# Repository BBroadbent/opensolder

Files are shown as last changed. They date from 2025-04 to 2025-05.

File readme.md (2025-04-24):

# OpenSolder
Fully open source JBC T245-compatible soldering station and tool holder  


## Introduction
When my cheap T12 clone soldering station went up in smoke, I started looking into either buying a JBC CDB, or building a proper soldering station. The internet is already crowded with DIY JBC compatible stations, but most are poorly documented, or does not have the quality-of-life features that the original have.

The [unisolder project](https://github.com/sparkybg/UniSolder-5.2) is very impressive, but way to complex and "universal" for my needs. [Marco Reps](https://youtu.be/GYIiOkr6x9o) built a cool C470 station that i liked the simplicity of, and this project is highly inspired by that.

## Goals:
- _T12 clone_ form factor that does not take up valuable bench space
- JBC T245 tip compatibility, with similar performance to the original station
- QoL features that the CDB station have, like auto standby, tip remover, holder, tip cleaner etc.
- Simple design using cheap off-the-shelf parts
- A compact handpiece stand with these features:
	- Detection when the handpiece is in the tool holder (auto standby)
	- Detection when you're about to swap tips (cut power)
	- Integrated tip remover, tip storage, tip cleaner and a soldering wire spool holder
	- Simple to build

## Design Specifications
- 24V toroidal transformer
- Zero Crossing AC switching
- OLED display and rotary encoder for adjusting temperature
- Compact and low profile design
- Super fast heatup time (~4s)
- Hardware should be mostly 3D printable, and easy to build using regular tools

## Station
  
The station is built in a Hammond enclosure, with a center mounted transformer. The PCB is mounted to the custom front panel, and all 230VAC connections is in the rear of the chassis.
There is two connectors on the rear panel, one for connecting to the stand, and an optional ST-link connector for firmware upgrades.

## Stand
  
The stand is made of 3D-printed parts, a genuine JBC tool holder, a tip remover made from aluminium angle and some fasteners. Most parts can be made from aluminium sheet if that is preferred.

## Schematic
This is the internal connections of the JBC C245 cartridge:  
  

[__The schematic__](https://github.com/howie-j/OpenSolder/raw/main/hardware/schematic.pdf) is divided into three sheets: AC, Analog and MCU.

### AC
The 24VAC input is fused, then connected directly to the tip center pin (5). Switching is done with two N-channel mosfets, driven by a Si8751 isolated gate driver.

Zero cross detection is done with an AC optocoupler, and the current is limited by three 10k resistors (to reduce BOM items). This solution triggers the ZeroCross about 90uS prematurely, and that is compensated for in firmware.

The MCU and thermocouple frontend must be electrically isolated, and a 24V to 5V DCDC PSU module solves that problem. The DCDC-supply is preregulated with a 24V linear regulator, and post-regulated to 3.3V with a LDO. This power supply chain is in need of some simplification, but the components are few and cheap, and it works great for now.

### Analog
The thermocouple signal is amplified with a MAX4238 chopper opamp, with a fairly arbitrary amplification of 221, since temperature calibration is done in firmware anyway. No negative supply rail means the thermocouple can't sense lower temperatures than room temp, but that's not needed for a soldering station.

Long handpiece wires means lots of crosstalk, so a pair of diodes clamps the thermocouple input at Vf. The MCU pin _TIP_CLAMP_ is driven low when power is applied to the handpiece, to clamp noise on the opamp input. When its time to measure tip temperature, the pin is set to input, and a delay waits for the RC filter to stabilize.

To sense if there is a tip cartridge in the handpiece, _TIP_CHECK_ is driven high. The low impedance of the thermocouple + heater (a few Ω's) will create a very low voltage drop. If the tip is removed, the Vf of the input protection diode will drive _THERMOCOUPLE_ADC_ close to 3.3V.

### MCU
A STM32F072 is used since I have a few of them in stock, but almost any STM32 could be adapted to work. To sense PCB temperature (and for cold junction compensation), an I2C temp sensor is added. The MCU might have an internal temperature sensor, but  have not looked into that yet.

The rotary encoder and handpiece stand inputs are filtered using plain RC filters. This, combined with the input hysteresis, removes most input noise. The TIM encoder inputs also have additional filtering and FSM redundancy.

## PCB
[___Check out this interactive BOM___](http://htmlpreview.github.io/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)

  
  
The PCB is quite low density, uses 0805 SMD components and is fully hand solderable with a microscope. Connections to the rear connectors (stand and ST-link) is done via a 6-pin IDC connector, so no crimping of tiny connector pins are necessary. The PCB is mounted to the front panel via the rotary encoder and the handpiece connector.

## Firmware
The firmware is simple and functional, and uses a modified hysteresis temperature controller that is very fast but has some initial overshoot. Currently all default values are set in _opensolder.h_, and are reset when the station is powered off.

### TODO
Nothing is currently missing for regular functionality. However some features would be cool to have:

- More accurate temp control (PID or other controller)
- User changeable default values
- Menu for changing default values
- Better looking UI

### B Broadbent TODO
- Pullup on zero cross line (external to STM32) (10k)

## Links and Sources
[The unisolder project](https://github.com/sparkybg/UniSolder-5.2)  
[Marco Reps](https://youtu.be/GYIiOkr6x9o)  
[foldvarid93's JBC Soldering Station](https://github.com/foldvarid93/JBC_SolderingStation)  
[johnmx's eevblog thread](https://eevblog.com/forum/testgear/jbc-soldering-station-cd-2bc-complete-schematic-analysis/)

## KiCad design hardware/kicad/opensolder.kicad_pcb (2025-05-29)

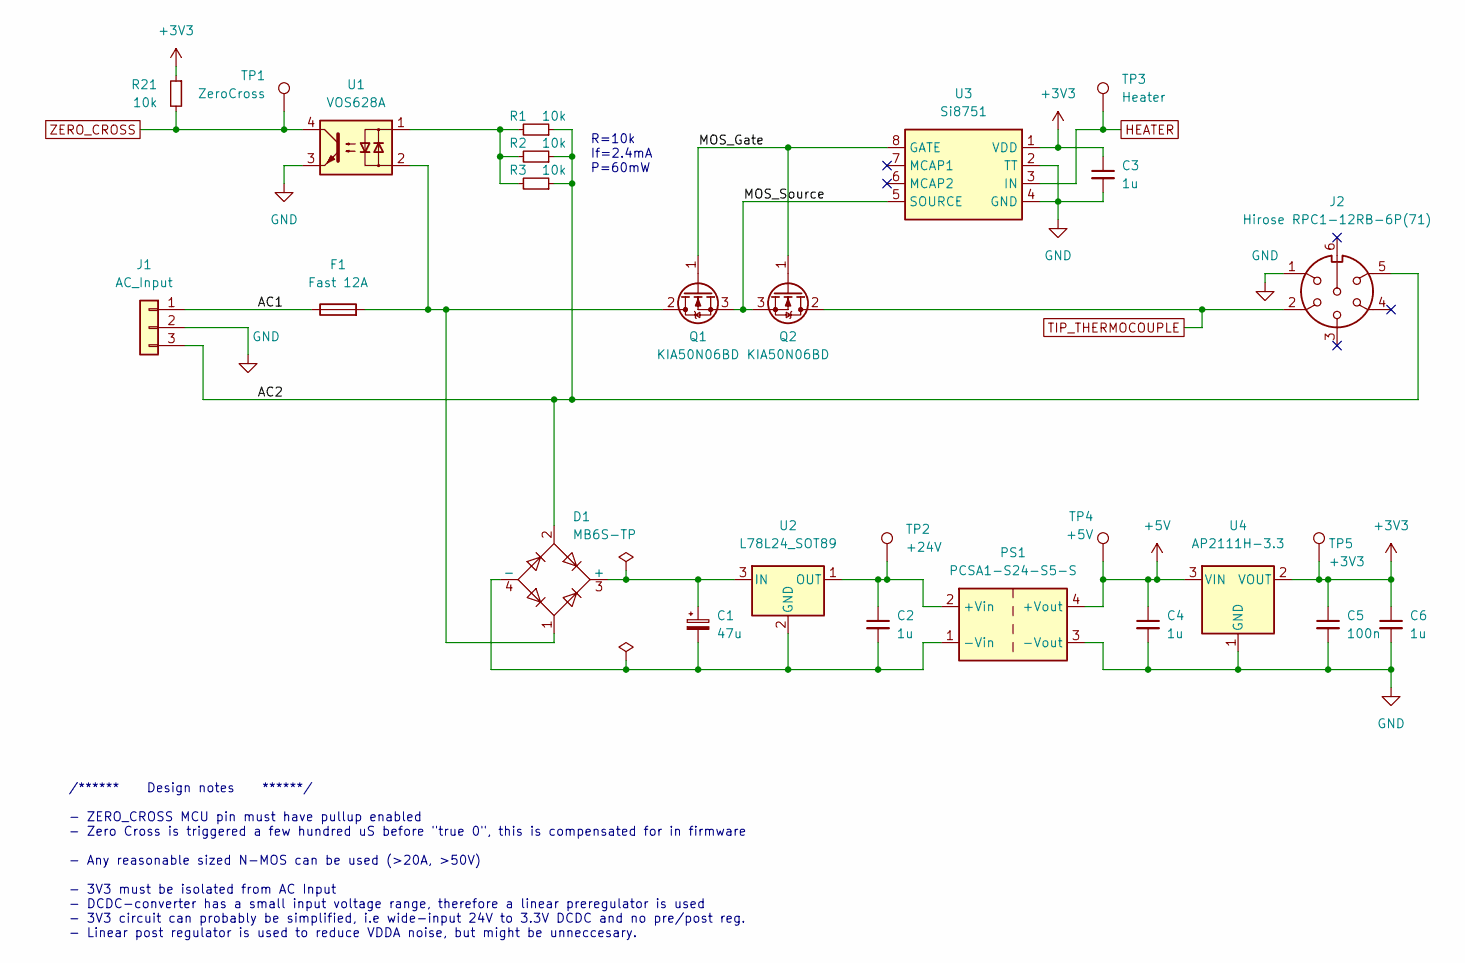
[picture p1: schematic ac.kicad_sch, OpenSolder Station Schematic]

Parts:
C1: 47u; CP_Radial_D8.0mm_P3.50mm
C2, C3, C4, C6: 1u; C_1210_3225Metric
C5: 100n; C_0805_2012Metric
D1: MB6S-TP; TO-269AA
F1: Fast 12A; Fuseholder_Cylinder-5x20mm_Schurter_0031_8201_Horizontal_Op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
J1: AC_Input; PhoenixContact_MSTBVA_2,5_3-G_1x03_P5.00mm_Vertical
J2: Hirose RPC1-12RB-6P(71); Hirose_RPC1
PS1: PCSA1-S24-S5-S; PDSE1_DCDC
Q1, Q2: KIA50N06BD; TO-252-2
R1, R2, R3, R21: 10k; R_0805_2012Metric
TP1: ZeroCross; TestPoint_Pad_D1.0mm
TP2: +24V; TestPoint_Pad_D1.0mm
TP3: Heater; TestPoint_Pad_D1.0mm
TP4: +5V; TestPoint_Pad_D1.0mm
TP5: +3V3; TestPoint_Pad_D1.0mm
U1: VOS628A; SOP-4_4.4x2.6mm_P1.27mm
U2: L78L24_SOT89; SOT-89-3
U3: Si8751; SOIC-8_3.9x4.9mm_P1.27mm
U4: AP2111H-3.3; SOT-223

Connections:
+3V3: C3.1, C5.1, C6.1, R21.1, TP5.1, U3.1 (VDD), U4.2 (VOUT); also elsewhere on the board
+5V: C4.1, PS1.4 (+Vout), TP4.1, U4.3 (VIN)
/AC/AC1: F1.1, J1.1
/AC/AC2: D1.2, J1.3, J2.5, R1.1, R2.1, R3.1
/AC/MOS_Gate: Q1.1 (G), Q2.1 (G), U3.8 (GATE)
/AC/MOS_Source: Q1.3 (S), Q2.3 (S), U3.5 (SOURCE)
GND: C3.2, C4.2, C5.2, C6.2, J1.2, J2.1, PS1.3 (-Vout), U1.3, U3.2 (TT), U3.4 (GND), U4.1 (GND); also elsewhere on the board
HEATER: TP3.1, U3.3 (IN); also elsewhere on the board
unnamed: C1.1, D1.3 (+), U2.3 (IN)
unnamed: C1.2, C2.2, D1.4 (-), PS1.1 (-Vin), U2.2 (GND)
unnamed: C2.1, PS1.2 (+Vin), TP2.1, U2.1 (OUT)
unnamed: D1.1, F1.2, Q1.2 (D), U1.2
unnamed: R1.2, R2.2, R3.2, U1.1
TIP_THERMOCOUPLE: J2.2, Q2.2 (D); also elsewhere on the board
ZERO_CROSS: R21.2, TP1.1, U1.4; also elsewhere on the board

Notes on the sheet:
R=10k If=2.4mA P=60mW
/****** Design notes ******/ - ZERO_CROSS MCU pin must have pullup enabled - Zero Cross is triggered a few hundred uS before "true 0", this is compensated for in firmware - Any reasonable sized N-MOS can be used (>20A, >50V) - 3V3 must be isolated from AC Input - DCDC-converter has a small input vo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

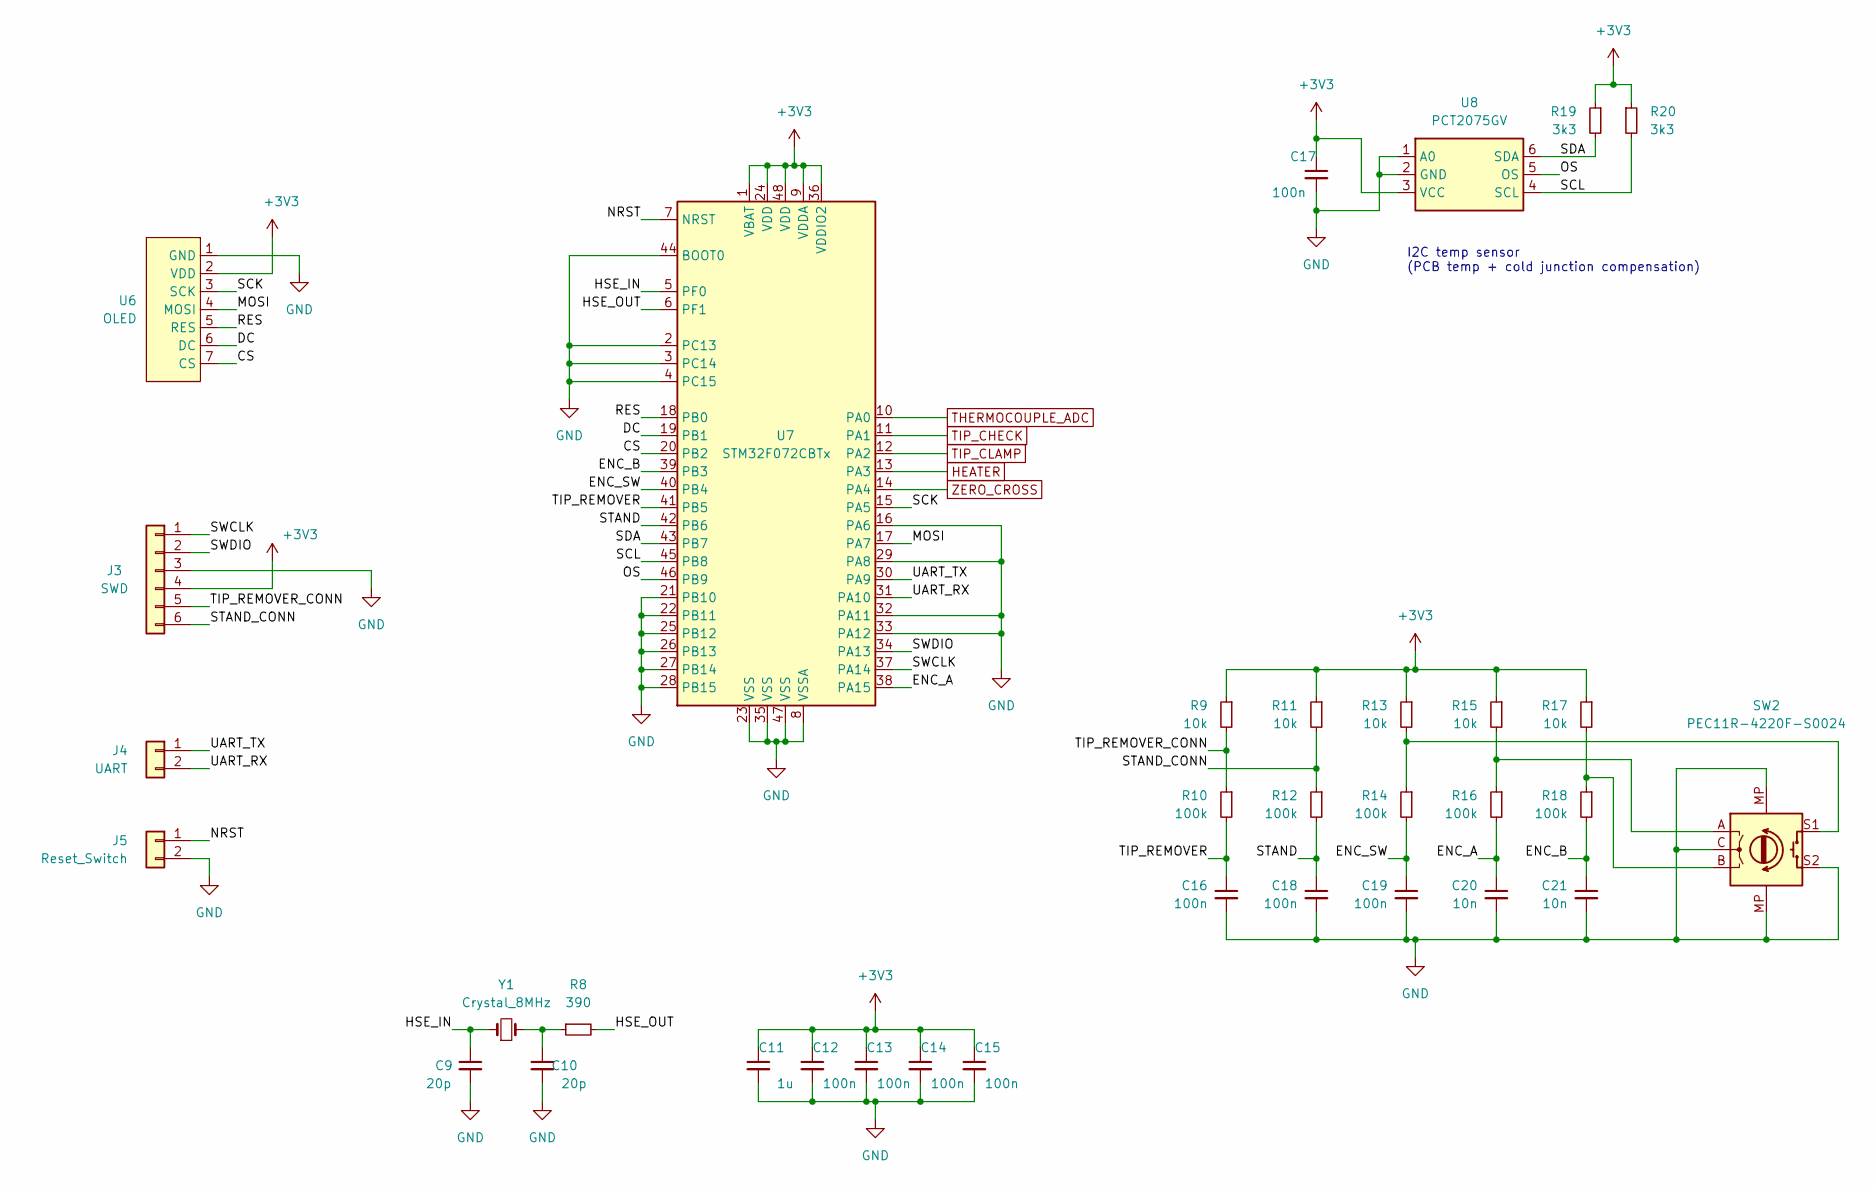
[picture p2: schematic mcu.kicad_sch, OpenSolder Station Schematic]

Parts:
C9, C10: 20p; C_0805_2012Metric
C11: 1u; C_1210_3225Metric
C12, C13, C14, C15, C16, C17, C18, C19: 100n; C_0805_2012Metric
C20, C21: 10n; C_0805_2012Metric
J3: SWD; IDC-Header_2x03_P2.54mm_Vertical
J4: UART; PinSocket_1x02_P2.54mm_Vertical
J5: Reset_Switch; PinSocket_1x02_P2.54mm_Vertical
R8: 390; R_0805_2012Metric
R9, R11, R13, R15, R17: 10k; R_0805_2012Metric
R10, R12, R14, R16, R18: 100k; R_0805_2012Metric
R19, R20: 3k3; R_0805_2012Metric
SW2: PEC11R-4220F-S0024; RotaryEncoder_PEC11R_PEC12R
U6: OLED; OLED_SSD1306_SPI_1.54
U7: STM32F072CBTx; LQFP-48_7x7mm_P0.5mm
U8: PCT2075GV; TSOP-6_1.65x3.05mm_P0.95mm
Y1: Crystal_8MHz; Crystal_SMD_HC49-SD

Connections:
+3V3: C11.1, C12.1, C13.1, C14.1, C15.1, C17.1, J3.4, R9.1, R11.1, R13.1, R15.1, R17.1, R19.1, R20.1, U6.2 (VDD), U7.1 (VBAT), U7.9 (VDDA), U7.24 (VDD), U7.36 (VDDIO2), U7.48 (VDD), U8.3 (VCC); also elsewhere on the board
/MCU/CS: U6.7 (CS), U7.20 (PB2)
/MCU/DC: U6.6 (DC), U7.19 (PB1)
/MCU/ENC_A: C20.1, R16.2, U7.38 (PA15)
/MCU/ENC_B: C21.1, R18.2, U7.39 (PB3)
/MCU/ENC_SW: C19.1, R14.2, U7.40 (PB4)
/MCU/HSE_IN: C9.1, U7.5 (PF0), Y1.1
/MCU/HSE_OUT: R8.2, U7.6 (PF1)
/MCU/MOSI: U6.4 (MOSI), U7.17 (PA7)
/MCU/NRST: J5.1, U7.7 (NRST)
/MCU/OS: U7.46 (PB9), U8.5 (OS)
/MCU/RES: U6.5 (RES), U7.18 (PB0)
/MCU/SCK: U6.3 (SCK), U7.15 (PA5)
/MCU/SCL: R20.2, U7.45 (PB8), U8.4 (SCL)
/MCU/SDA: R19.2, U7.43 (PB7), U8.6 (SDA)
/MCU/STAND: C18.1, R12.2, U7.42 (PB6)
/MCU/STAND_CONN: J3.6, R11.2, R12.1
/MCU/SWCLK: J3.1, U7.37 (PA14)
/MCU/SWDIO: J3.2, U7.34 (PA13)
/MCU/TIP_REMOVER: C16.1, R10.2, U7.41 (PB5)
/MCU/TIP_REMOVER_CONN: J3.5, R9.2, R10.1
/MCU/UART_RX: J4.2, U7.31 (PA10)
/MCU/UART_TX: J4.1, U7.30 (PA9)
GND: C9.2, C10.2, C11.2, C12.2, C13.2, C14.2, C15.2, C16.2, C17.2, C18.2, C19.2, C20.2, C21.2, J3.3, J5.2, SW2.C, SW2.MP, SW2.S2, U6.1 (GND), U7.2 (PC13), U7.3 (PC14), U7.4 (PC15), U7.8 (VSSA), U7.16 (PA6), U7.21 (PB10), U7.22 (PB11), U7.23 (VSS), U7.25 (PB12), U7.26 (PB13), U7.27 (PB14), U7.28 (PB15), U7.29 (PA8), U7.32 (PA11), U7.33 (PA12), U7.35 (VSS), U7.44 (BOOT0), U7.47 (VSS), U8.1 (A0), U8.2 (GND); also elsewhere on the board
HEATER: U7.13 (PA3); also elsewhere on the board
unnamed: C10.1, R8.1, Y1.2
unnamed: R13.2, R14.1, SW2.S1
unnamed: R15.2, R16.1, SW2.A
unnamed: R17.2, R18.1, SW2.B
THERMOCOUPLE_ADC: U7.10 (PA0); also elsewhere on the board
TIP_CHECK: U7.11 (PA1); also elsewhere on the board
TIP_CLAMP: U7.12 (PA2); also elsewhere on the board
ZERO_CROSS: U7.14 (PA4); also elsewhere on the board

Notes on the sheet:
I2C temp sensor (PCB temp + cold junction compensation)

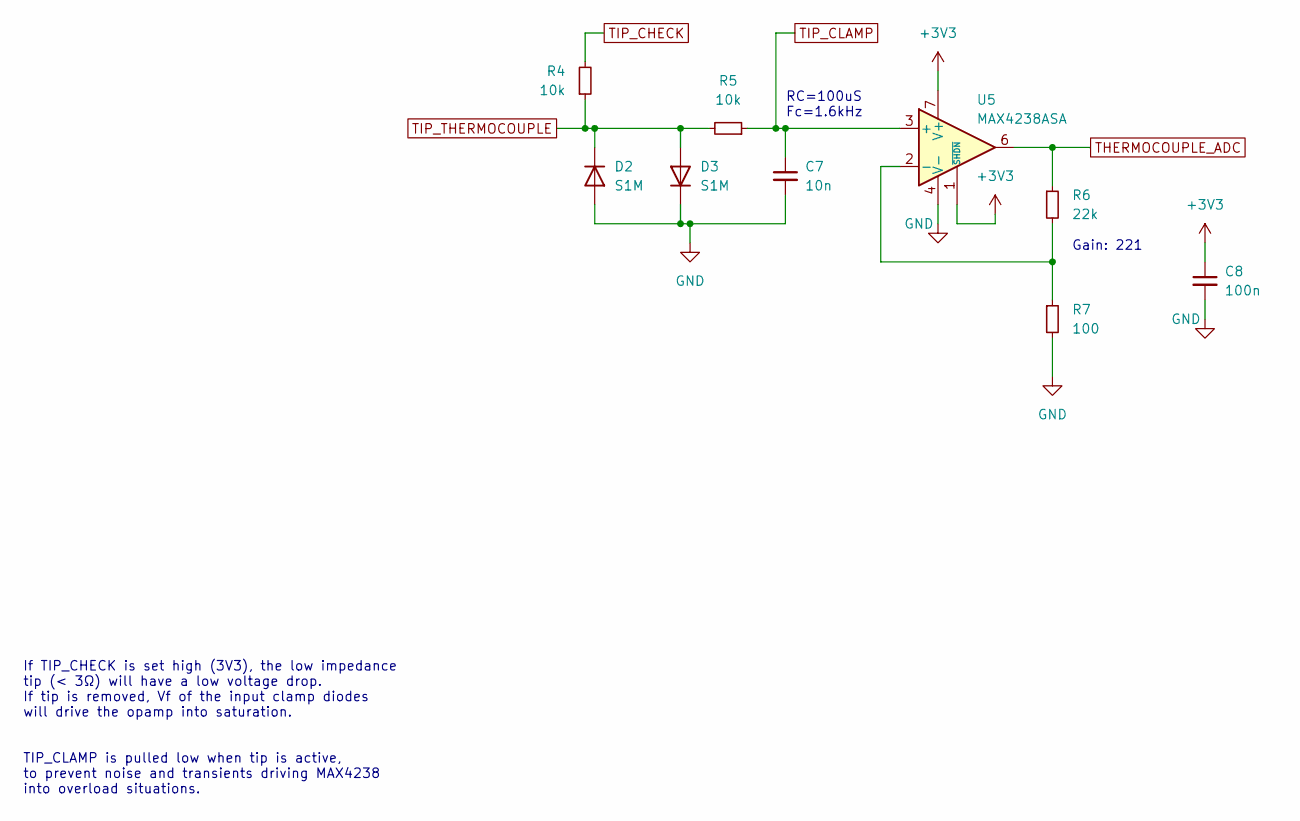
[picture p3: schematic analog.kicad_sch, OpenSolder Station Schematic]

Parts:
C7: 10n; C_0805_2012Metric
C8: 100n; C_0805_2012Metric
D2, D3: S1M; D_SMA
R4, R5: 10k; R_0805_2012Metric
R6: 22k; R_0805_2012Metric
R7: 100; R_0805_2012Metric
U5: MAX4238ASA; SOIC-8_3.9x4.9mm_P1.27mm

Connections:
+3V3: C8.1, U5.1 (~SHDN), U5.7 (V+); also elsewhere on the board
GND: C7.2, C8.2, D2.2 (A), D3.1 (K), R7.2, U5.4 (V-); also elsewhere on the board
unnamed: R6.2, R7.1, U5.2 (-)
THERMOCOUPLE_ADC: R6.1, U5.6; also elsewhere on the board
TIP_CHECK: R4.2; also elsewhere on the board
TIP_CLAMP: C7.1, R5.1, U5.3 (+); also elsewhere on the board
TIP_THERMOCOUPLE: D2.1 (K), D3.2 (A), R4.1, R5.2; also elsewhere on the board

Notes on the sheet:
Gain: 221
RC=100uS Fc=1.6kHz
If TIP_CHECK is set high (3V3), the low impedance tip (< 3Ω) will have a low voltage drop. If tip is removed, Vf of the input clamp diodes will drive the opamp into saturation. TIP_CLAMP is pulled low when tip is active, to prevent noise and transients driving MAX4238 into overload situations.

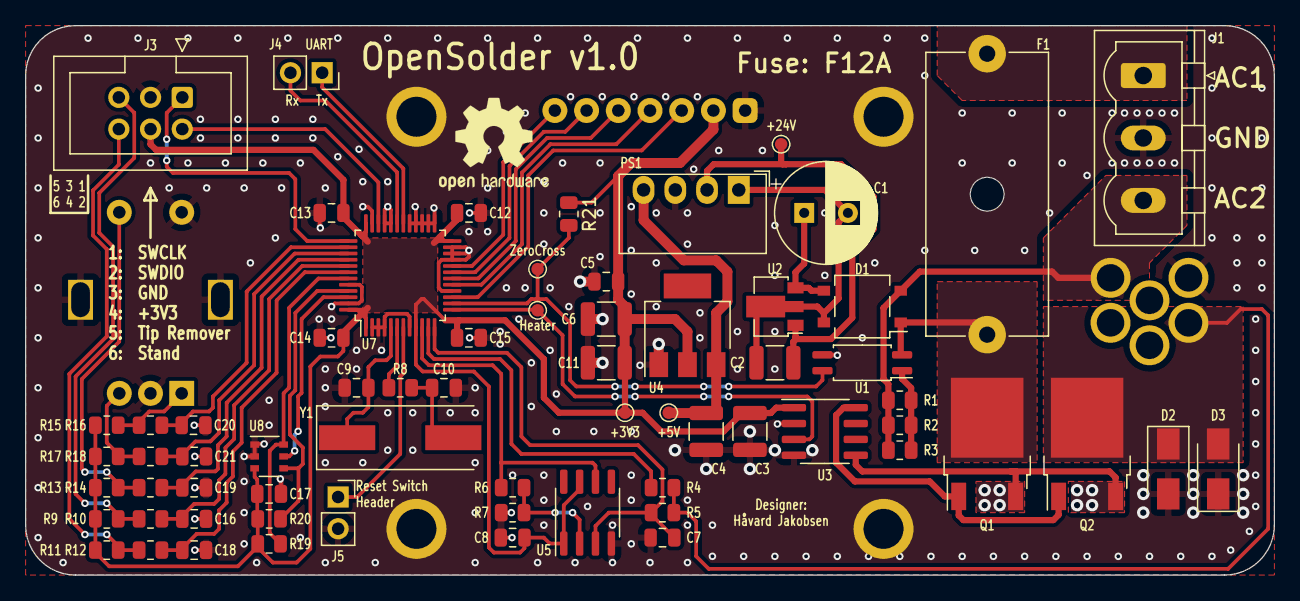
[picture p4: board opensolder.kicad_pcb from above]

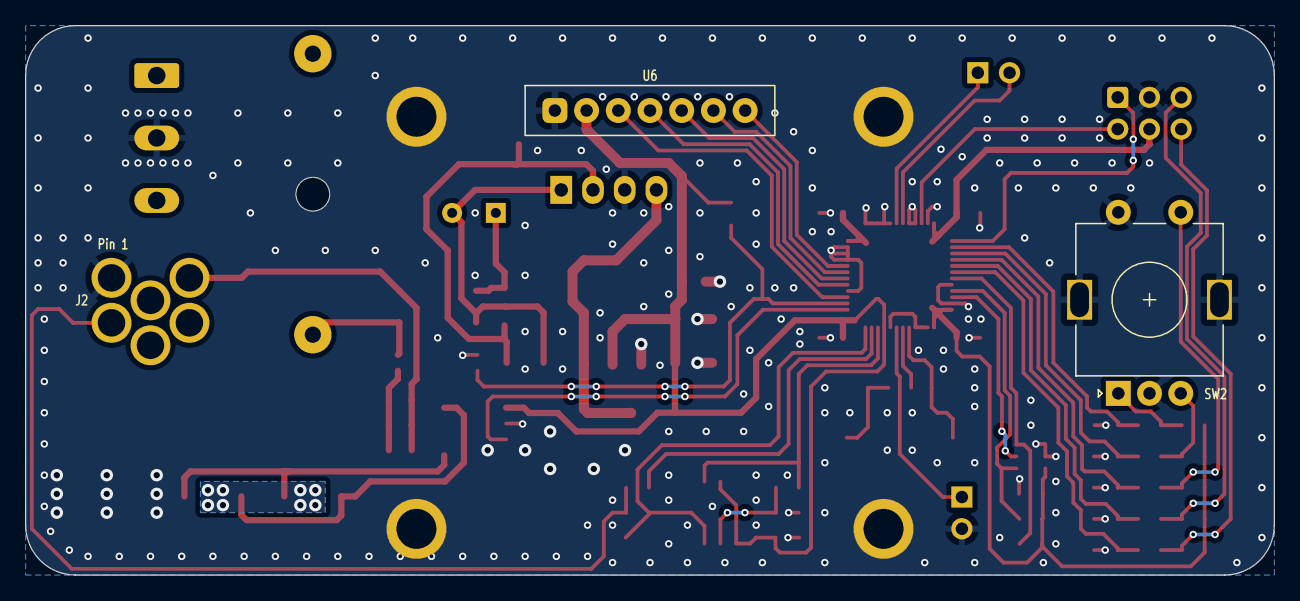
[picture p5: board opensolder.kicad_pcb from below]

Board: 2 copper layers, 100.0 x 44.0 mm, 69 parts (3 on the bottom side), 45 nets.

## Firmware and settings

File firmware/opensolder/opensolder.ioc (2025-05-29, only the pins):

Mcu.UserName=STM32F072CBTx
PA0.GPIO_Label=THERMOCOUPLE_ADC
PA0.Signal=ADC_IN0
PA1.GPIO_Label=TIP_CHECK
PA1.Signal=GPIO_Input
PA10.Signal=USART1_RX
PA13.Signal=SYS_SWDIO
PA14.Signal=SYS_SWCLK
PA15.GPIO_Label=ENC_A
PA15.Signal=S_TIM2_CH1_ETR
PA2.GPIO_Label=TIP_CLAMP
PA2.Signal=GPIO_Input
PA3.GPIO_Label=HEATER
PA3.Signal=GPIO_Output
PA4.GPIO_Label=ZERO_CROSS
PA4.Signal=GPXTI4
PA5.Signal=SPI1_SCK
PA7.Signal=SPI1_MOSI
PA9.Signal=USART1_TX
PB0.GPIO_Label=RES
PB0.Signal=GPIO_Output
PB1.GPIO_Label=DC
PB1.Signal=GPIO_Output
PB2.GPIO_Label=CS
PB2.Signal=GPIO_Output
PB3.GPIO_Label=ENC_B
PB3.Signal=S_TIM2_CH2
PB4.GPIO_Label=ENC_SW
PB4.Signal=GPIO_Input
PB5.GPIO_Label=TIP_REMOVER
PB5.Signal=GPIO_Input
PB6.GPIO_Label=STAND
PB6.Signal=GPIO_Input
PB7.Signal=I2C1_SDA
PB8.Signal=I2C1_SCL
PB9.GPIO_Label=OS
PB9.Signal=GPIO_Input
PF0-OSC_IN.Signal=RCC_OSC_IN
PF1-OSC_OUT.Signal=RCC_OSC_OUT

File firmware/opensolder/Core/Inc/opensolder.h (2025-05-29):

/*
 * opensolder.h
 *
 * License: GPL-3.0 or any later version
 * Copyright (c) 2022 Håvard Jakobsen
 */

#ifndef OPENSOLDER_H
#define OPENSOLDER_H

/******    Includes    ******/
#include "main.h"
#include <stdint.h>

/******    Constants   ******/
enum PCT2075_constants {
	PCT2075_I2C_ADDR = 0x92U, // 1001 001 << 1
	PCT2075_TEMP_REG = 0x00U, // Temperature register pointer
	PCT2075_CONF_REG = 0x01U, // Configuration register pointer
	PCT2075_HYST_REG = 0x02U, // Hysteresis register pointer
	PCT2075_OS_REG = 0x03U,	  // Over-temperature shutdown register pointer
	PCT2075_IDLE_REG = 0x01U  // Idle register pointer
};

enum opensolder_constants {
	TIP_CHECK_INTERVAL = 50,		   // Number of half mains cycles between each tip check (value of 50 cycles * 10ms = 500ms tipcheck interval)
	TIP_CHANGE_DELAY_MS = 2000,		   // Delay after tip_change_sense is set before turning heater on
	DISPLAY_BRIGHTNESS = 255,		   // Sets display contrast/brightness, value 0-255
	DISPLAY_UPDATE_TICKS = 500,		   // Refresh rate for updating tip_temp, set higher to remove jitter
	DISPLAY_MESSAGE_TIMEOUT_MS = 2000, // How long to display messages
	STR_ARRAY_MAX_LEN = 128 / 6 + 1,	   // Display text string array max length (including '\0'.
	SPLASHSCREEN_TIMEOUT_MS = 1000,	   // Splash screen / boot screen, 0 to disable
	DEFAULT_TEMP = 320,				   // Default set temp on startup
	MAX_TEMP = 420,					   // Maximum allowable temperature
	MIN_TEMP = 30,					   // Minimum allowable temperature
	TEMP_STEPS = 5,					   // Number of degrees setTemp changes per encoder step
	MAX_ON_PERIODS = 4,				   // Maximum number if AC half cycles the power should be on before next temp reading
	STANDBY_TEMP = 160,				   // Tip temperature when handle is in holder
	STANDBY_TIME_S = 300,			   // Number of seconds to keep tip at elevated standby temperature, before turning heater off
	STANDBY_DELAY_MS = 300,			   // Delay from lifting the tool holder before turning heater on
	ADC_BUFFER_LENGTH = 50,			   // Number of ADC samples to take every reading
	ADC_MAX_DEVIATION = 200,		   // Maximum deviation allowed in the ADC sample buffer. Any value out of range gives the reading an error
	ADC_NO_TIP_MIN_VALUE = 4000,	   // Lowest expected temp reading with no tip inserted and TIP_CHECK pin high. Used for tip detection
	ADC_TIP_MAX_VALUE = 3800,		   // Max expected temp reading with tip inserted. Must be higher that MAX_TEMP reading. Used for tip detection
	AC_DETECTION_INTERVAL_MS = 12	   // Max expected time between each AC interrupt
};

enum opensolder_messages {
	OFF = 0,
	ON = 1,
	WAIT,
	TIP_DETECTED,
	TIP_NOT_DETECTED,
	TIP_CHECK_ERROR,
	AC_NOT_DETECTED,
	OVERHEATING,
	ADC_READING_ERROR = 999 // Constant to check tip_temp for an error. Also displays 999 on display in case of a reading error
};

enum my_states { INIT_STATE, TIP_CHANGE_STATE, OFF_STATE, ON_STATE, STANDBY_STATE, ERROR_STATE };

/******    Global Variables    ******/
extern ADC_HandleTypeDef hadc;
extern I2C_HandleTypeDef hi2c1;
extern TIM_HandleTypeDef htim2;
extern TIM_HandleTypeDef htim6;
extern TIM_HandleTypeDef htim7;
extern UART_HandleTypeDef huart1;

/******    Global Function Declarations    ******/
void opensolder_init(void);
void opensolder_main(void);
void sensor_scan(void);
uint8_t get_system_state(void);

#endif

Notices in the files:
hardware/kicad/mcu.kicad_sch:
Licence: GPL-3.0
